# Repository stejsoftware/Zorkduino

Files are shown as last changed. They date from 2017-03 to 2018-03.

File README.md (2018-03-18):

# Zorkduino 

### Play Zork on your TV with an Arduino.

Who doesn’t love Zork?. Who doesn’t love Arduinos? Why not grab a few cheap components and build an Arduino gadget capable of playing all the classic Infocom games on your TV from the comfort of your couch.

Title

A few years ago I ported a Z-Machine player to a [little arduino-like device](http://rossumblog.com/2011/04/19/zork-for-the-microtouch/). Ever since I have been meaning to get around to a project that would work on a TV with a real keyboard and once again rekindle fond memories of long nights playing Zork on my Atari 800.

### You will need:

* Arduino UNO, Pro, Pro Mini or equivalent.
* SD card or micro SD card + breakout board (from Adafruit, eBay etc).
* RCA A/V Cable (eBay).
* 470ohm, 1k and 100k resistors.
* Breadboard, wires etc.
* WebTV or MsnTV IR Keyboard or PS2 a nasty old PS2 keyboard (eBay).
* IR receiver TSOP38238,TSOP4838 or equivalent (Adafruit, Mouser etc).

## Building it

The schematic is very simple:

```
        +----------------+           +-----------------+
        |                |           |                 |
        |             13 |-----------| SCK    micro\SD |
        |             12 |-----------| MISO   card     |
        |             11 |-----------| MOSI   module   |
        |             10 |-----------| CS              |
        |                |      5v <-|                 |
        |                |     GND <-|                 |
        |    arduino     |           +-----------------+
        |    uno/pro     |
        |                |       5v <--+-+   IR Receiver
        |                |      GND <--|  )  TSOP4838 etc.
        |              8 |-------------+-+
        |                |
        |              6 |----[ 100k ]--------> AUDIO
        |                |
        |              9 |----[  1k  ]----+---> VIDEO
        |                |                |
        |              1 |----[ 470  ]----+
        |                |
        |              3 |----------------> *PS2 CLOCK
        |              2 |----------------> *PS2 DATA
        |                |
        +----------------+
```
### Layout on an Arduino Uno...

uno

### ...and on a Mini Pro.

ProMini

Just about any SD card or microsd card breakout will do. Some of the very cheap ones (<$1) don't have 5v to 3v3 level converters and may fry your SD card so caveat emptor. As always, Adafruit has nice ones.

WebTV keyboards come in various guises: WebTV, MsnTV, Displayer, UltimateTV etc. They all should work just fine. A few places have the nice Philips variant new for $11.95 w/ free shipping (search for 'SWK-8630'). This one comes with a nice PS2 IR receiver; more on it later.

keyboards

IR receivers come in a number of different forms. You are looking for a 38khz version with a known pinout: Some have the center pin as GND, some as V+. Make sure you know what kind you have. When in doubt, Adafruit.

I like using iPhone/iPod video cables for TV projects. Because they no longer work (their MFI chip long since revoked) they are inexpensive, are labeled internally and have a strain relief grommet.

If you have an IR keyboard then good for you. If not, connect your nasty old PS2 clock and data lines to pins 3 and 2 then order an IR keyboard.

### On the disk

The [`stories`](stories) folder contains a `zd.mem` pagefile along with several sample games:

`tutorial.z3` Introduction to interactive fiction and a little bit of Zork I

`sampler1.z5`
Samples of Planetfall, Infidel, and The Witness.

`sampler2.z3`
Samples of  Zork I, Leather Goddesses of Phobos, and Trinity

`minizork.z3`
A nice big chunk of Zork I that was given away with the British Commodore users' magazine "Zzap! 64" no. 67. in 1990.

Copy these files to a freshly formatted sd or microsd card. You can find lots of other Zorkduino compatible games at the [Interactive Fiction Archive](http://www.ifarchive.org/). Insert the card and run the `zorkduino.ino` sketch from the [`zorkduino`](.) folder. When it is all up and running, it should look like this (depending on how many games you found):

(https://www.youtube.com/watch?feature=player_embedded&v=-4dWXJrqxUk)

## How it works

Squeezing Zork into the limited footprint of an Arduino proved to be a bit of a challenge. The code uses a port of Mark Howell and John Holder's JZIP, a Z-machine interpreter. The Z-machine was created in 1979 to play large (100k!) adventure games on small (8K!) personal computers. Long before Java the implementors at Infocom built a virtual machine capable of paging, loading and saving complete runtime state that ran on a wide variety of CPUs. Clever stuff.

The trouble is the Arduino only has 2k of ram. The Z-machine interpreter uses 2k for its stack alone, leaving no room for dynamic memory, disk buffers, video frame buffers, avr stack and other program state. The solution is to virtualize all stack and memory accesses from the interpreter down to a 160 byte cache and a 512 byte disk buffer. Thats where the `zd.mem` file comes in - a megabyte or so of virtual stack, memory and save-game slots.

Virtualizing everything slows things down a bit but serendipitously makes the Arduino perform at roughly the same speed as my old Atari 800. Video needs 912 bytes for the frame buffer, leaving ~464 bytes for the avr stack and all application and interpreter state.

### Video

The video is generated with a simple state machine on the Timer1 ISR. HSYNC interrupts occur at 15.73kHz and trigger state changes for video, audio and keyboard state machines.

Active video is 308x192 pixels, 38x24 8x8 charaters. Getting this resolution requires use of the UART in SPI mode running at top (8Mhz) speed to shift out pixels from either a character font (the Atari 800 default font) or a graphics font (an extravagant waste of 2k logo). Because the video is being emitted from the TX pin it is fun to open the serial monitor to watch what ntsc video looks like as text: almost at bit Matrixy.

### Audio

No homage to 70's and 80's computing would be complete without keyboard beeps and disk thweeps. Keystrokes generate a 1000hz feedback beep, sd card writes make a 3600hz mechanical click. These sounds are generated in the video isr by toggling pin 6 after a certain number of HSYNCs.

### Keyboard

WebTV IR is an unusual UART-like asych serial protocol. It runs at ~660 baud with 3.25 start bits, a 10 bit class code, 8 bit key code, parity and stop bit. Class codes are things like keyup, keydown etc. and key codes map physical keyboard layout. The video ISR counts HSYNCs between transitions on the IR data line and passes state change events to the keyboard code. 

The PS2 code is pretty conventional. A good explanation is [here](http://www.computer-engineering.org/ps2protocol/).

## Extra Credit

If you get the Philips $11.95 keyboard variant you get a PS2 IR receiver as well. The receiver can be...

* used as-is as a PS2 keyboard connected to pins 2 and 3.
* gutted and turned into a nice case.

I prefer the latter. The case has a nice slot in the back with a sliding door that is perfect for a microSD card. It has a nice IR window at the front and a TSOP31238 (5V center pin) IR receiver that can be harvested from the PCB. Get a cheap Pro/Mini + microsd breakout, add that iPod video cable and it looks like this:

case

Drop me a line at rossumur@gmail.com if you have any trouble.

cheers

[rossumblog.com](http://rossumblog.com)

p.s. The maze in minizork is not the same layout as in Zork I. I have it if you need it.

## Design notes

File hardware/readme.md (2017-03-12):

# Zorkduino Shield

Eagle schematics and PCB for a Shield compatible with Arduino UNO. It features:

* PS/2 keyboard connector
* USB-A female, alternative mount for USB keyboards that can revert to PS/2 mode
* SD Card Connector
* Micro SD (alternative mount) Card Connector
* Dual RCA connector for Audio/Video
* P2 Stereo Jack (alternative mount) for Audio/Video 
* Infrared Receiver
* Reset Button

The connectors were disposed so all the wired connections are on the same side while the SD 
socket and the Infrared receiver are on the opposite side. This should make the device more
easy to be used and hence easier to put in a box.

The board was manually routed.

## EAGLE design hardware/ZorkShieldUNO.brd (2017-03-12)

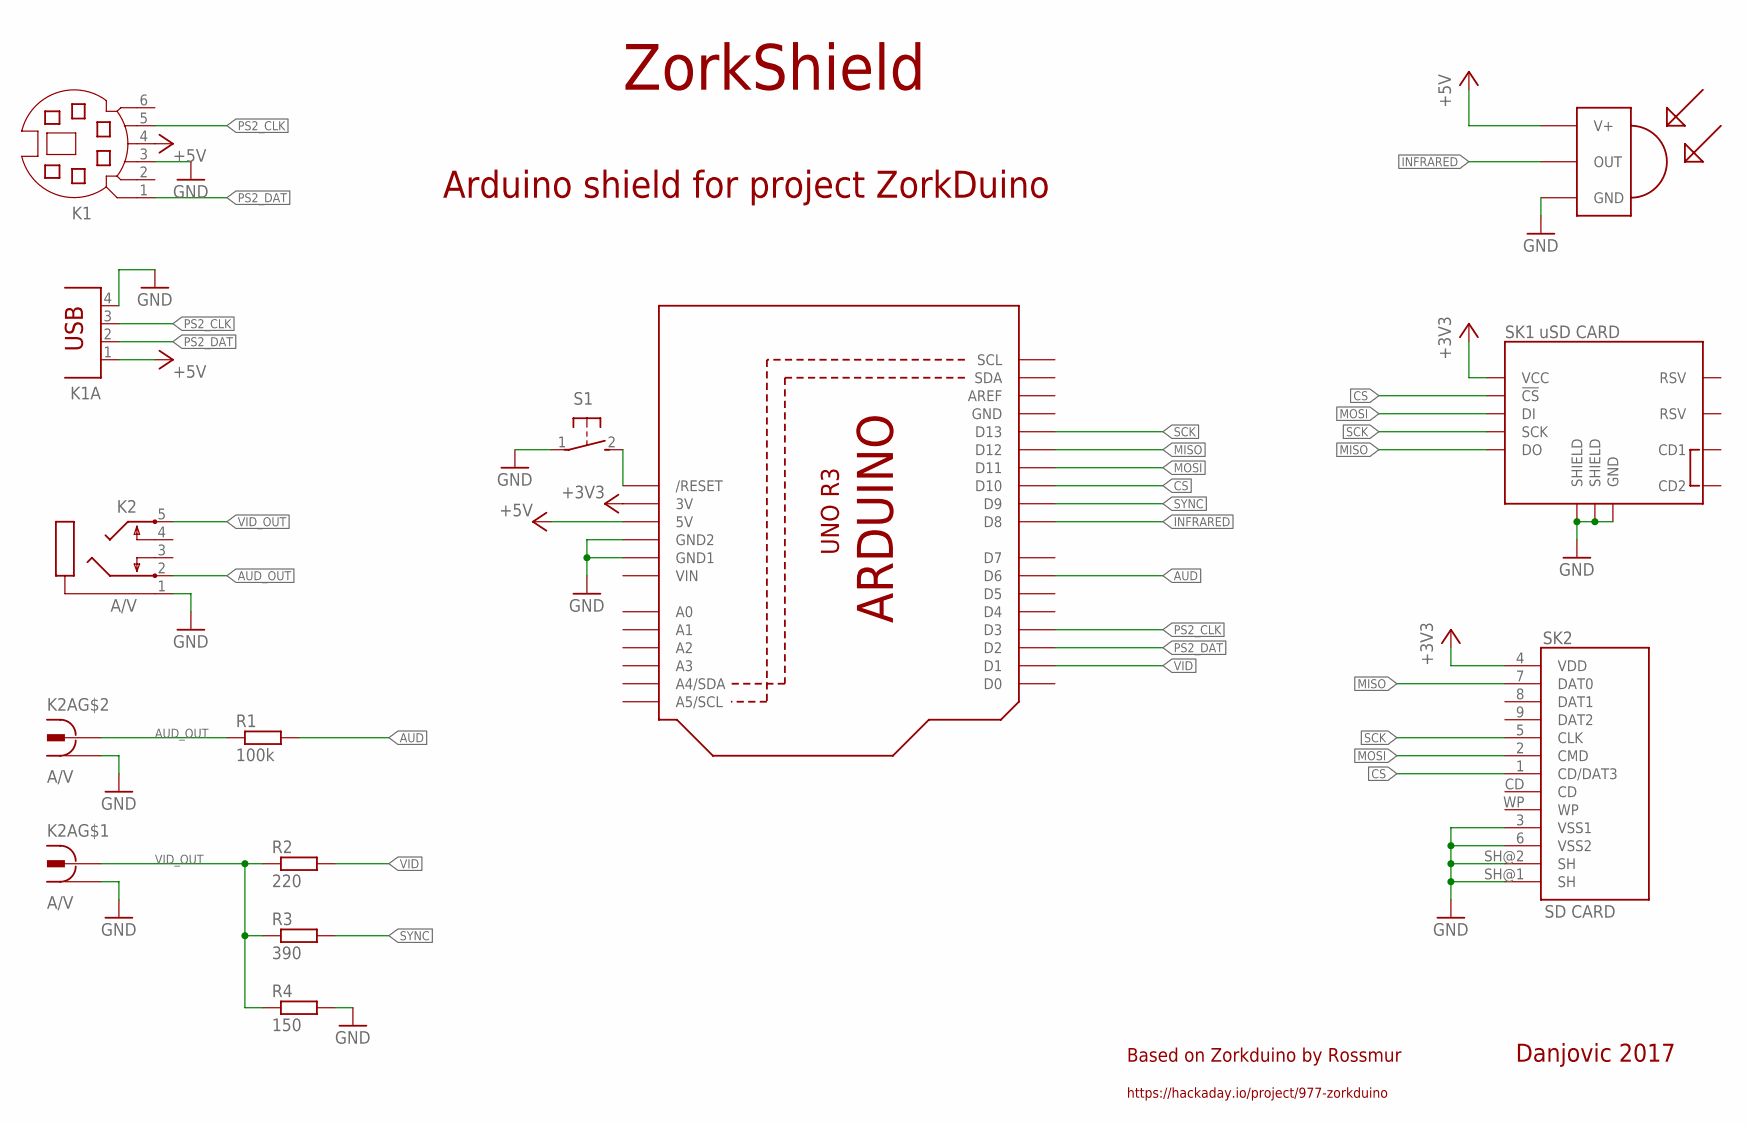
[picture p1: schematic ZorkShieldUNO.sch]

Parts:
IR1: TSOP4837; TSOP18XX
K1: MD06SS; MDIN06SS
K1A: PN87520
K2: A/V; PG203J
K2A: A/V; DOUBLE_VERTICAL_2
Q1: ARDUINOR3-NOIOREF-NOTEXT; ARDUINOR3-NOTEXT-NOIOREF
R1: 100k; 0204/7
R2: 220; 0204/7
R3: 390; 0204/7
R4: 150; 0204/7
S1: 31-XX; B3F-31XX
SK1: uSD CARD; MICRO-SD-SOCKET-PP
SK2: SD CARD; SDCARD_4UCONN

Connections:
+3V3: Q1.3V, SK1.VCC, SK2.4 (VDD)
+5V: IR1.VCC (V+), K1.4, K1A.1, Q1.5V
AUD: Q1.D6, R1.2
AUD_OUT: K2.2, K2A.LS (2), R1.1
CS: Q1.D10, SK1.CS (!CS), SK2.1 (CD/DAT3)
GND: IR1.GND, K1.3, K1A.4, K2.1, K2A.HG (1), K2A.LG (1), Q1.GND, Q1.GND1, Q1.GND2, R4.2, S1.1, SK1.GND, SK1.GND1 (SHIELD), SK1.GND3 (SHIELD), SK2.3 (VSS1), SK2.6 (VSS2), SK2.SH@1 (SH), SK2.SH@2 (SH)
INFRARED: IR1.OUT, Q1.D8
MISO: Q1.D12, SK1.DO, SK2.7 (DAT0)
MOSI: Q1.D11, SK1.DI, SK2.2 (CMD)
unnamed: Q1.RESET (/RESET), S1.2 (S)
PS2_CLK: K1.5, K1A.3, Q1.D3
PS2_DAT: K1.1, K1A.2, Q1.D2
SCK: Q1.D13, SK1.SCLK (SCK), SK2.5 (CLK)
SYNC: Q1.D9, R3.2
VID: Q1.D1, R2.2
VID_OUT: K2.5, K2A.HS (2), R2.1, R3.1, R4.1
VIN: Q1.VIN

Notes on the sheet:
Arduino shield for project ZorkDuino
ZorkShield
Based on Zorkduino by Rossmur
Danjovic 2017
https://hackaday.io/project/977-zorkduino

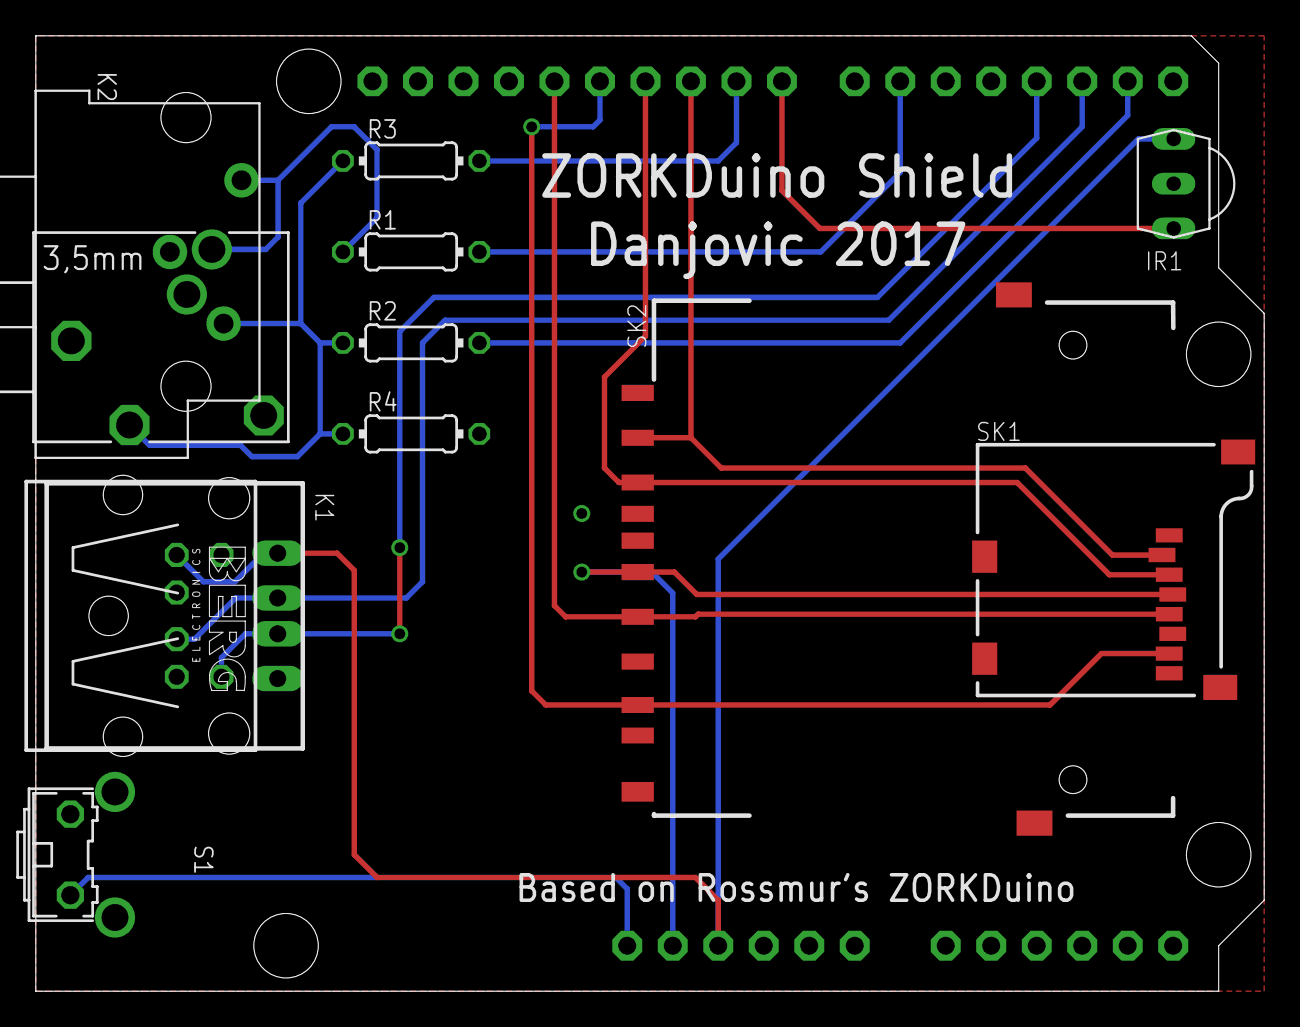
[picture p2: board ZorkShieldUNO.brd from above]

Board: 2 copper layers, 68.6 x 53.3 mm, 13 parts (0 on the bottom side), 16 nets.

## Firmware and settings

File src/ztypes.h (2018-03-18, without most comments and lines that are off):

#define __ZTYPES_INCLUDED
#if defined(AIX)
#define _POSIX_SOURCE
#define POSIX
#endif
#if defined(__MSDOS__)
#define MSDOS
#endif
#include <assert.h>
#include <ctype.h>
#include <stdio.h>
#include <stdlib.h>
#include <string.h>
#include <stdint.h>
#ifdef __linux__
#include <execinfo.h>
#endif
#ifdef ARDUINO
#include <Arduino.h>
#undef PROGMEM
#define PROGMEM __attribute__((section(".progmem.data")))
#else
#define PROGMEM
#define char char
#define pgm_read_byte(_x) *(_x)
#define strcpy_P strcpy
#endif
#define SAVE_SIZE           ((64+2)*1024L)
#define SAVE_SLOTS          10
#define STACK_REGION_OFFSET 0
#define GAME_REGION_OFFSET  (STACK_REGION_OFFSET + 2048L)
#define SAVE_REGION_OFFSET  (GAME_REGION_OFFSET + 256*1024L)
#define MEMORY_FILE_SIZE    (SAVE_REGION_OFFSET + SAVE_SLOTS*SAVE_SIZE)
#define TEXT_COLS 38
#define TEXT_ROWS 24
extern uint8_t _fdata[TEXT_ROWS*TEXT_COLS];
extern void zdInit();
extern void zdLoop();
#define ILLEGAL_OPERATION           1
#define BAD_FRAME_FOR_UNWIND        2
#define WRONG_GAME_OR_VERSION       3
#define UNSUPPORTED_ZCODE_VERSION   4
#define NO_SUCH_PROPERTY            5
#if defined(MSDOS)
#include <malloc.h>
#endif
#define JZIPVER "JZIP V2.0.1g"
#define JZIPRELDATE "Tue, 5 Dec 1995"
extern unsigned char JTERP;
#define DEFAULT_ROWS 24
#define DEFAULT_COLS 80
#define DEFAULT_RIGHT_MARGIN 0
#define DEFAULT_TOP_MARGIN 0
#define NBBY 8
#define TRUE 1
#define FALSE 0
#define FILENAME_MAX 255
#define PATHNAME_MAX 1024
#define EXIT_SUCCESS 0
#define EXIT_FAILURE 1
#define SEEK_SET 0
#define SEEK_END 2
#ifdef unix
#define strchr(a, b) index (a, b)
#if defined (HAVE_BCOPY)
#define memmove(a, b, c) bcopy (b, a, c)
#else
#define memmove(a, b, c) memcpy ((a), (b), (c))
#endif
#define const
#endif
typedef unsigned char zbyte_t;
typedef unsigned short zword_t;
typedef struct zheader {
    zbyte_t type;
    zbyte_t config;
    zword_t version;
    zword_t data_size;
    zword_t start_pc;
    zword_t words_offset;
    zword_t objects_offset;
    zword_t globals_offset;
    zword_t restart_size;
    zword_t flags;
    zbyte_t release_date[6];
    zword_t synonyms_offset;
    zword_t file_size;
    zword_t checksum;
    zbyte_t interpreter;
    zbyte_t interpreter_version;
    zbyte_t screen_rows;
    zbyte_t screen_columns;
    zbyte_t screen_left;
    zbyte_t screen_right;
    zbyte_t screen_top;
    zbyte_t screen_bottom;
    zbyte_t max_char_width;
    zbyte_t max_char_height;
    zword_t filler1[3];
    zword_t function_keys_offset;
    zword_t filler2[2];
    zword_t alternate_alphabet_offset;
    zword_t mouse_position_offset;
    zword_t filler3[4];
} zheader_t;
#define H_TYPE 0
#define H_CONFIG 1
#define CONFIG_BYTE_SWAPPED 0x01
#define CONFIG_COLOUR       0x01
#define CONFIG_TIME         0x02
#define CONFIG_MAX_DATA     0x04
#define CONFIG_TANDY        0x08
#define CONFIG_EMPHASIS     0x08
#define CONFIG_NOSTATUSLINE 0x10
#define CONFIG_WINDOWS      0x20
#define H_VERSION 2
#define H_DATA_SIZE 4
#define H_START_PC 6
#define H_WORDS_OFFSET 8
#define H_OBJECTS_OFFSET 10
#define H_GLOBALS_OFFSET 12
#define H_RESTART_SIZE 14
#define H_FLAGS 16
#define SCRIPTING_FLAG 0x01
#define FIXED_FONT_FLAG 0x02
#define REFRESH_FLAG 0x04
#define GRAPHICS_FLAG 0x08
#define SOUND_FLAG 0x10
#define UNDO_AVAILABLE_FLAG 0x10
#define COLOUR_FLAG 0x40
#define NEW_SOUND_FLAG 0x80
#define H_RELEASE_DATE 18
#define H_SYNONYMS_OFFSET 24
#define H_FILE_SIZE 26
#define H_CHECKSUM 28
#define H_INTERPRETER 30
#define INTERP_GENERIC 0
#define INTERP_DEC_20 1
#define INTERP_APPLE_IIE 2
#define INTERP_MACINTOSH 3
#define INTERP_AMIGA 4
#define INTERP_ATARI_ST 5
#define INTERP_MSDOS 6
#define INTERP_CBM_128 7
#define INTERP_CBM_64 8
#define INTERP_APPLE_IIC 9
#define INTERP_APPLE_IIGS 10
#define INTERP_TANDY 11
#define INTERP_UNIX 12
#define INTERP_VMS 13
#define H_INTERPRETER_VERSION 31
#define H_SCREEN_ROWS 32
#define H_SCREEN_COLUMNS 33
#define H_SCREEN_LEFT 34
#define H_SCREEN_RIGHT 35
#define H_SCREEN_TOP 36
#define H_SCREEN_BOTTOM 37
#define H_MAX_CHAR_WIDTH 38
#define H_MAX_CHAR_HEIGHT 39
#define H_FILLER1 40
#define H_FUNCTION_KEYS_OFFSET 46
#define H_FILLER2 48
#define H_ALTERNATE_ALPHABET_OFFSET 52
#define H_MOUSE_POSITION_OFFSET 54
#define H_FILLER3 56
#define V1 1
#define V2 2
#define V3 3
typedef struct zobjectv3 {
    zword_t attributes[2];
    zbyte_t parent;
    zbyte_t next;
    zbyte_t child;
    zword_t property_offset;
} zobjectv3_t;
#define O3_ATTRIBUTES 0
#define O3_PARENT 4
#define O3_NEXT 5
#define O3_CHILD 6
#define O3_PROPERTY_OFFSET 7
#define O3_SIZE 9
#define PARENT3(offset) (offset + O3_PARENT)
#define NEXT3(offset) (offset + O3_NEXT)
#define CHILD3(offset) (offset + O3_CHILD)
#define P3_MAX_PROPERTIES 0x20
#define V4 4
typedef struct zobjectv4 {
    zword_t attributes[3];
    zword_t parent;
    zword_t next;
    zword_t child;
    zword_t property_offset;
} zobjectv4_t;
#define O4_ATTRIBUTES 0
#define O4_PARENT 6
#define O4_NEXT 8
#define O4_CHILD 10
#define O4_PROPERTY_OFFSET 12
#define O4_SIZE 14
#define PARENT4(offset) (offset + O4_PARENT)
#define NEXT4(offset) (offset + O4_NEXT)
#define CHILD4(offset) (offset + O4_CHILD)
#define P4_MAX_PROPERTIES 0x40
#define V5 5
#define V6 6
#define V7 7
#define V8 8
#define STOP 0
#define RUN 1
#define FUNCTION 0x0000
#define PROCEDURE 0x0100
#define ASYNC 0x0200
#define ARGS_MASK 0x00ff
#define TYPE_MASK 0xff00
#define PAGE_SIZE 512
#define PAGE_MASK 511
#define PAGE_SHIFT 9
#define STACK_SIZE 1024
#define ON 1
#define OFF 0
#define RESET -1
#define SCREEN 255
#define TEXT_WINDOW 0
#define STATUS_WINDOW 1
#define MIN_ATTRIBUTE 0
#define NORMAL 0
#define REVERSE 1
#define BOLD 2
#define EMPHASIS 4
#define FIXED_FONT 8
#define MAX_ATTRIBUTE 8
#define TEXT_FONT 1
#define GRAPHICS_FONT 3
#define FOREGROUND 0
#define BACKGROUND 1
#define GAME_RESTORE 0
#define GAME_SAVE 1
#define GAME_SCRIPT 2
#define GAME_RECORD 3
#define GAME_PLAYBACK 4
#define UNDO_SAVE 5
#define UNDO_RESTORE 6
#define MAX_TEXT_SIZE 8
zbyte_t get_byte(unsigned long offset);
zword_t get_word(unsigned long offset);
void set_byte(zword_t offset,zbyte_t value);
void set_word(zword_t offset,zword_t value);
extern int GLOBALVER;
extern zbyte_t h_type;
extern zbyte_t h_config;
extern zword_t h_version;
extern zword_t h_data_size;
extern zword_t h_start_pc;
extern zword_t h_words_offset;
extern zword_t h_objects_offset;
extern zword_t h_globals_offset;
extern zword_t h_restart_size;
extern zword_t h_flags;
extern zword_t h_synonyms_offset;
extern zword_t h_file_size;
extern zword_t h_checksum;
extern zbyte_t h_interpreter;
extern zbyte_t h_interpreter_version;
extern zword_t h_alternate_alphabet_offset;
extern uint8_t story_scaler;
extern uint8_t story_shift;
extern uint8_t property_mask;
extern uint8_t property_size_mask;
extern void PUSH(zword_t v);
extern zword_t POP();
extern zword_t STACK(zword_t i);
extern void STACK(zword_t i,zword_t v);
extern zword_t sp;
extern zword_t fp;
extern unsigned long pc;
extern uint8_t interpreter_state;
extern int interpreter_status;
extern uint8_t screen_window;
extern uint8_t formatting;
extern uint8_t outputting;
extern uint8_t redirecting;
extern uint8_t scripting;
extern uint8_t scripting_disable;
extern uint8_t recording;
extern uint8_t replaying;
#define FORMATTING  1
#define OUTPUTTING  2
#define REDIRECTING 4
#define SCRIPTING   8
#define RECORDING   16
#define REPLAYING   32
#define STATUS_ACTIVE   64
extern uint8_t state_flags;
extern uint8_t status_active;
extern uint8_t status_size;
extern int8_t char_count;
#define right_margin    0
#define left_margin     0
#define top_margin      0
#define screen_cols     TEXT_COLS
#define screen_rows     TEXT_ROWS
extern uint8_t lines_written;
extern uint8_t status_pos;
extern char *line;
extern char *status_line;
char lookup_table(uint8_t i, uint8_t c);
extern char monochrome;
extern int hist_buf_size;
extern char bigscreen;
#ifdef __STDC__
void check_argument (zword_t);
int call (int, zword_t *, int);
void get_fp (void);
void jump (zword_t);
void restart (void);
void ret (zword_t);
void unwind (zword_t, zword_t);
#else
void check_argument ();
int call ();
void get_fp ();
void jump ();
void restart ();
void ret ();
void unwind ();
#endif
#ifdef __STDC__
void close_record (void);
void close_script (void);
void close_story (void);
unsigned int get_story_size (void);
void open_playback (int);
void open_record (void);
void open_script (void);
int playback_key (void);
int playback_line (int, char *, int *);
void read_page (int, void *);
void record_key (int);
void record_line (const char *);
int restore (void);
int save (void);
void script_char (int);
void script_string (const char *);
void script_line (const char *);
void script_new_line (void);
void undo_restore (void);
void undo_save (void);
void verify (void);
#else
void close_record ();
void close_script ();
void close_story ();
unsigned int get_story_size ();
void open_playback ();
void open_record ();
void open_script ();
void open_story ();
int playback_key ();
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

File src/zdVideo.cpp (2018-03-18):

/* Copyright (c) 2010-2014, Peter Barrett
 **
 ** Permission to use, copy, modify, and/or distribute this software for
 ** any purpose with or without fee is hereby granted, provided that the
 ** above copyright notice and this permission notice appear in all copies.
 **
 ** THE SOFTWARE IS PROVIDED "AS IS" AND THE AUTHOR DISCLAIMS ALL
 ** WARRANTIES WITH REGARD TO THIS SOFTWARE INCLUDING ALL IMPLIED
 ** WARRANTIES OF MERCHANTABILITY AND FITNESS. IN NO EVENT SHALL THE AUTHOR
 ** BE LIABLE FOR ANY SPECIAL, DIRECT, INDIRECT, OR CONSEQUENTIAL DAMAGES
 ** OR ANY DAMAGES WHATSOEVER RESULTING FROM LOSS OF USE, DATA OR PROFITS,
 ** WHETHER IN AN ACTION OF CONTRACT, NEGLIGENCE OR OTHER TORTIOUS ACTION,
 ** ARISING OUT OF OR IN CONNECTION WITH THE USE OR PERFORMANCE OF THIS
 ** SOFTWARE.
 */

// Video output, audio tone generation and IR keyboard scanning events

#include "ztypes.h"

//__attribute__((section(".progmem.data")))
const unsigned char atascii[] = {
#include "zdFont.h"  // SWIZZLED ATARI FONT
#include "zdLogofont.h"  // Zork logo
};

// PORT B
#define SYNC_PIN    1
#define IR_PIN      0

// PORT D
#define AUDIO_PIN       6
#define PS2_CLOCK_PIN   3
#define PS2_DATA_PIN    2
#define VIDEO_PIN       1

// ~1016 cpu clocks per line at 16Mhz
#define USEC(_x)         (((_x)*F_CPU/1000000)-1)
#define TICKS_SCANLINE   USEC(63.555)
#define TICKS_HSYNC      USEC(4.7)
#define TICKS_LONG_HSYNC USEC(63.555-4.7)
#define TICKS_HBLANK     USEC(10.30)

#define BLANK_LINES 40
#define ACTIVE_LINES (TEXT_ROWS*8)

#define STATE_VBLANK  0
#define STATE_PRE     1
#define STATE_ACTIVE  2
#define STATE_POST    3

// does not do halfline sync during blanking
__attribute__((section(".progmem.data")))
char v_lines[] = { 3,BLANK_LINES,ACTIVE_LINES,262-(3+BLANK_LINES+ACTIVE_LINES) };

// Video State
uint8_t v_state = 0;
uint8_t v_count = 0;
uint8_t v_vbicountdown = 0;
uint8_t _fdata[TEXT_COLS*TEXT_ROWS];    // Framebuffer

// Audio state
uint8_t a_count = 0;
uint8_t a_freq = 0;
uint8_t a_cycles = 0;

// IR state
uint8_t ir_last = 0;
uint8_t ir_count = 0;

//==========================================================
//==========================================================
//  Webtv keyboard

// Report changes on IR pin to keyboard handler
// t is HSYNCH ticks
void keyboardIREvent(uint8_t t, uint8_t v); 

//==========================================================
//==========================================================
// PS2 keyboard

void enable_ps2();
void disable_ps2();

//==========================================================
//==========================================================
//  audio for keyboard/io feedback

void audio_beep(uint8_t freq, uint8_t cycles)
{
  a_freq = freq;
  a_cycles = cycles;
  a_count = freq;
}

//==========================================================
//==========================================================
//  Video ISR

static void inline tick_align(uint8_t tick)
{
  __asm__ __volatile__ (
      "sub	%[tick], %[tcnt1l]\n"
"loop: subi	%[tick], 3\n"
      "brcc	loop\n"
      "cpi      %[tick],-3\n"
      "breq     done\n"
      "cpi      %[tick],-2\n"
      "brne     .\n"
"done:\n"
      :: [tick] "a" (tick),
      [tcnt1l] "a" (TCNT1L)
    );
}

// Video ISR
// Handles video and audio generation as well as keyboard scanning
ISR(TIMER1_OVF_vect)
{
  uint8_t ir = PINB & 1;
  OCR1A = v_state ? TICKS_HSYNC : TICKS_LONG_HSYNC;
  
  if (v_state == STATE_ACTIVE)
  {
    UDR0 = 0;
    UCSR0C = (1<<USBS0)|(3<<UCSZ00);
    tick_align(TICKS_HBLANK);
    UCSR0B = 1<<TXEN0;

    uint8_t line = ACTIVE_LINES-v_count;
    uint8_t* src = _fdata + (line >> 3)*TEXT_COLS;
    uint16_t font = (uint16_t)atascii + ((line&7) << 8); // + fontv*TEXT_COLS

    // If a line starts with a 1, use the logofont
    uint16_t n = src[0] == 1;
    font += n<<11;

    // Delay by some chars to center text
    uint8_t a,i,c;
    a = 2;
    while (a--) {
        UDR0 = 0;
        i = 4;
        while (i--)
            ;
    }
    UCSR0C = (1<<UMSEL01)|(1<<UMSEL00)|(0<<UCPHA0)|(0<<UCPOL0); // START SPI MODE
    
    // 40 character output
    i = 0;
    a = TEXT_COLS;
    while (a--)
    {
        c = src[i++];  // zero byte line ending - early out. Simple CPU recovery strategy.
        if (!c)
          break;
        UDR0 = pgm_read_byte(font+c);
        asm("nop");
    }

    UDR0 = 0;
    UCSR0B = 0;
  }

  // Advance video state machine
  if (!--v_count)
  {
    v_state = (v_state+1) & 3;
    v_count = pgm_read_byte(v_lines + v_state);
    if (v_state == STATE_ACTIVE)
    {
      disable_ps2();         // don't field ps2 keyboard interrupts during active video
      if (v_vbicountdown)
          v_vbicountdown--;  // VBI countdown timer
    }
    else if (v_state == STATE_POST)
        enable_ps2();
  }

  // ir keyboard
  if (ir != ir_last)
  {
    keyboardIREvent(ir_count,ir_last);
    ir_count = 0;
    ir_last = ir;
  }
  if (ir_count != 0xFF)
    ir_count++;
    
  // audio out
  if (a_cycles && !--a_count)
  {
    --a_cycles;
    a_count = a_freq;
    PORTD ^= _BV(6);
  }
}

void start_video()
{
    UBRR0H = 0;  // Fastest serial clock  
    UBRR0L = 0;
        
    DDRB |= _BV(SYNC_PIN);
    DDRB &= ~_BV(IR_PIN);
    DDRD |= _BV(AUDIO_PIN) | _BV(VIDEO_PIN);
    PORTD &= ~_BV(VIDEO_PIN);  // black when serial port is not driving TX

    // Set OC1A on Compare Match, Fast PWM, No prescaling, Timer 1
    TCCR1A = _BV(COM1A1) | _BV(COM1A0) | _BV(WGM11);
    TCCR1B = _BV(WGM13) | _BV(WGM12) | _BV(CS10);
    ICR1 = TICKS_SCANLINE;
    OCR1A = TICKS_HSYNC; 
    TIMSK1 = _BV(TOIE1);
    PORTD = 0;
    v_state = 3;
    v_count = 1;
    sei();
}

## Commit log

2017-03-12 Added Eagle files for the Zorkduino shield
    [ZorkShieldUNO.brd, ZorkShieldUNO.sch]
2018-03-18 moving files around
    [ZorkShieldUNO.brd, ZorkShieldUNO.sch]

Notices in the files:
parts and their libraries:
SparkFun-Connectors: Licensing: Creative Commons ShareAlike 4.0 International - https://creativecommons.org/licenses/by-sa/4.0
